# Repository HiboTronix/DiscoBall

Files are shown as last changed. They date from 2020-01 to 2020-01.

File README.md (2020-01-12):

# Discoball 
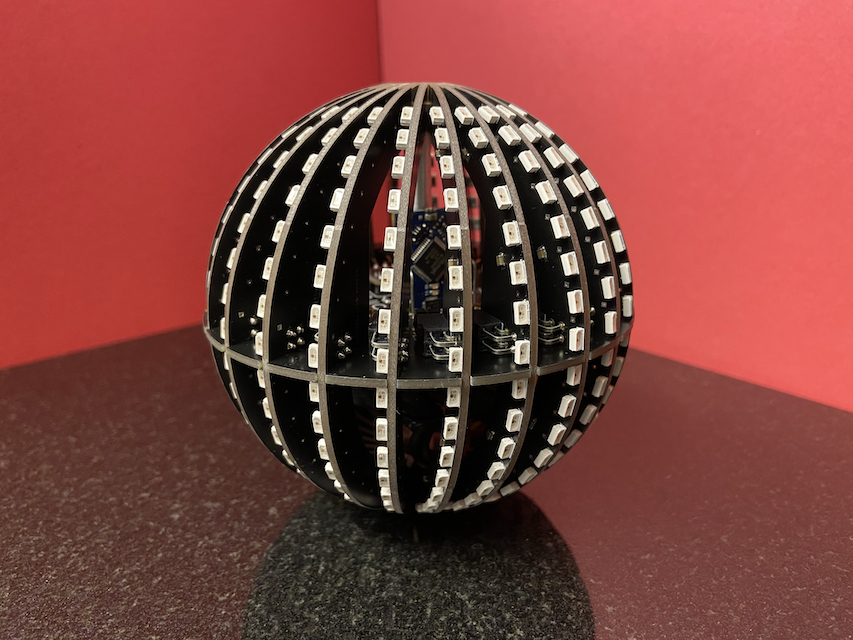
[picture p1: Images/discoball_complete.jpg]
DiscoBall

</p>Here are the DIY files so you can build your own DiscoBall.
There are 3 main parts to DiscoBall, the centre, the alignment caps and the ribs.
These files don't include a portable power solution.  I used a dc-dc converter, a lipo battery and charger that I could fit inside.</p>
<p>An Adafruit Powerboost1000  with a TP4056 lipo charger (with protection) should be ample if you use the standard brightness of 10.</p>
</p>Reference images are in the images folder.</p>
</p>Arduino IDE setup instructions are in the Software folder.</p>
</p>All the parts you require including the Gerbers required to have the PCBs manufactured are above, start by reading the assembly pdf.</p>
</p></p>
</p>I wish you luck and I'd love to see it if you make one, catch me on Twitter(@HiboTronix) and/or tag it with #Discoball : )</p>
<p><br />This work is licensed under a <a rel="license" href="http://creativecommons.org/licenses/by-sa/3.0/">Creative Commons Attribution-ShareAlike 3.0 Unported License</a>.</p>

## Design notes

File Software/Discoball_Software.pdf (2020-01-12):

# HiboTronix DiscoBall Software

The DiscoBall uses the Arduino Nano Every with the Arduino IDE.
The Library used to communicate with the LSM6DS3 is from Sparkfun, please use the guide below to install and use the “MinimalistExample” sketch in the examples folder to test the Accelerometer and Gyro.

https://learn.sparkfun.com/tutorials/lsm6ds3-breakout-hookup-guide/all#
(*Communication by I2C, address= 0x6B, INT1 connected to D4 on the Arduino)

The NeoPixels are controlled by the Adafruit NeoPixel Library:

https://learn.adafruit.com/adafruit-neopixel-uberguide/the-magic-of-neopixels

Please Install and run the “Strandtest” sketch in the examples folder with the following settings:

And also:

Power consumption at brightness 10 is approximately 550mA. If you are powering from USB and you select a higher brightness it will probably destroy your USB port.

Full brightness is approximately 6A at full white!!

The rest of the programming is up to you I’m afraid, good luck ;)

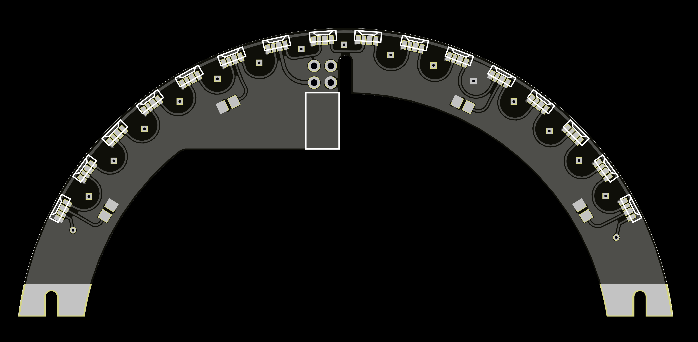
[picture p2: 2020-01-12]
Images/DiscoBall_Rib_PCB.png

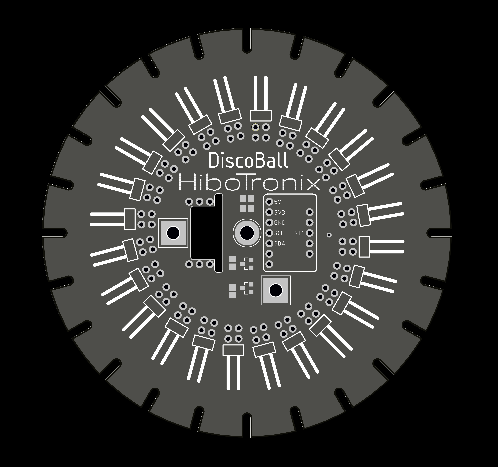
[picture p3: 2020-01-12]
Images/DiscoBall_Centre_PCB.png

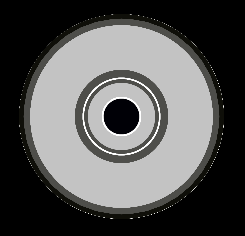
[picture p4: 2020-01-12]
Images/DiscoBall_Caps.png

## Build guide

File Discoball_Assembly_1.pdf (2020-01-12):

# HiboTronix Discotiall Assembly

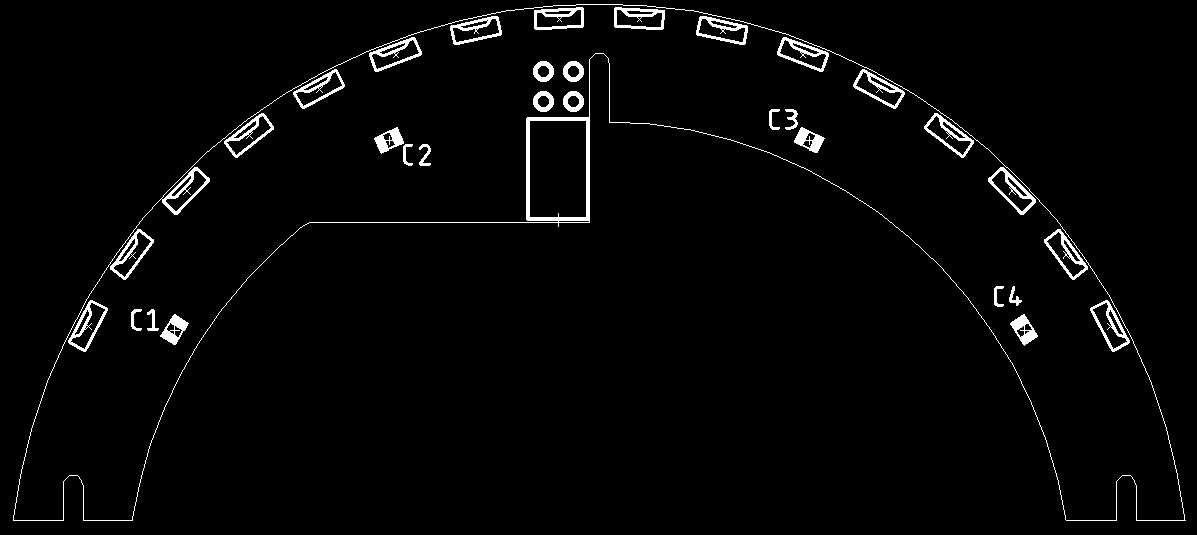
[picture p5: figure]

## Parts Required:

## SMD Components

## Other Items

(These LEDs can be obtained from AliExpress and EBAY, possibly other places too!)

## PCB And Stencil

You need the following:

24x Discotiall LED Ribs PCBs

Gerber files can be found on GitHub (https://github.com/HiboTronix/Discoball)

Files for the LED Ribs are in folder: Disctiall_Rib_PCB.zip Files for the SMD stencil are in folder: Discotiall_Rib_Stencil.zip

## Assembly:

1) Paste and assemble SMD components to board
Designator | Part | Qty | Example Link
C1,C2,C3,C4 | 0805 100nF(0.1uF) CAPACITOR | 96 | Digikey (https://www.digikey.com/short/zc128h)
Description | Qty
SK6812-SIDE-4020 LEDs | 384

2) Place the 2x2 pin header in the PCB from the LED side, using something to hold it aligned with the edge of the board and the silkscreen, solder it in.
3) Repeat 24 times.
4) My advice would be to test each rib individually before final assembly, I had an old Arduino UNO with some male to male Dupont cables as a temporary test jig.

Once you have 24 assembled and tested ribs, use the instructions in Discotiall_Assembly_2.pdf to complete your Discotiall.

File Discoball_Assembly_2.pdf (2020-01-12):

# HiboTronix DiscoBall Assembly

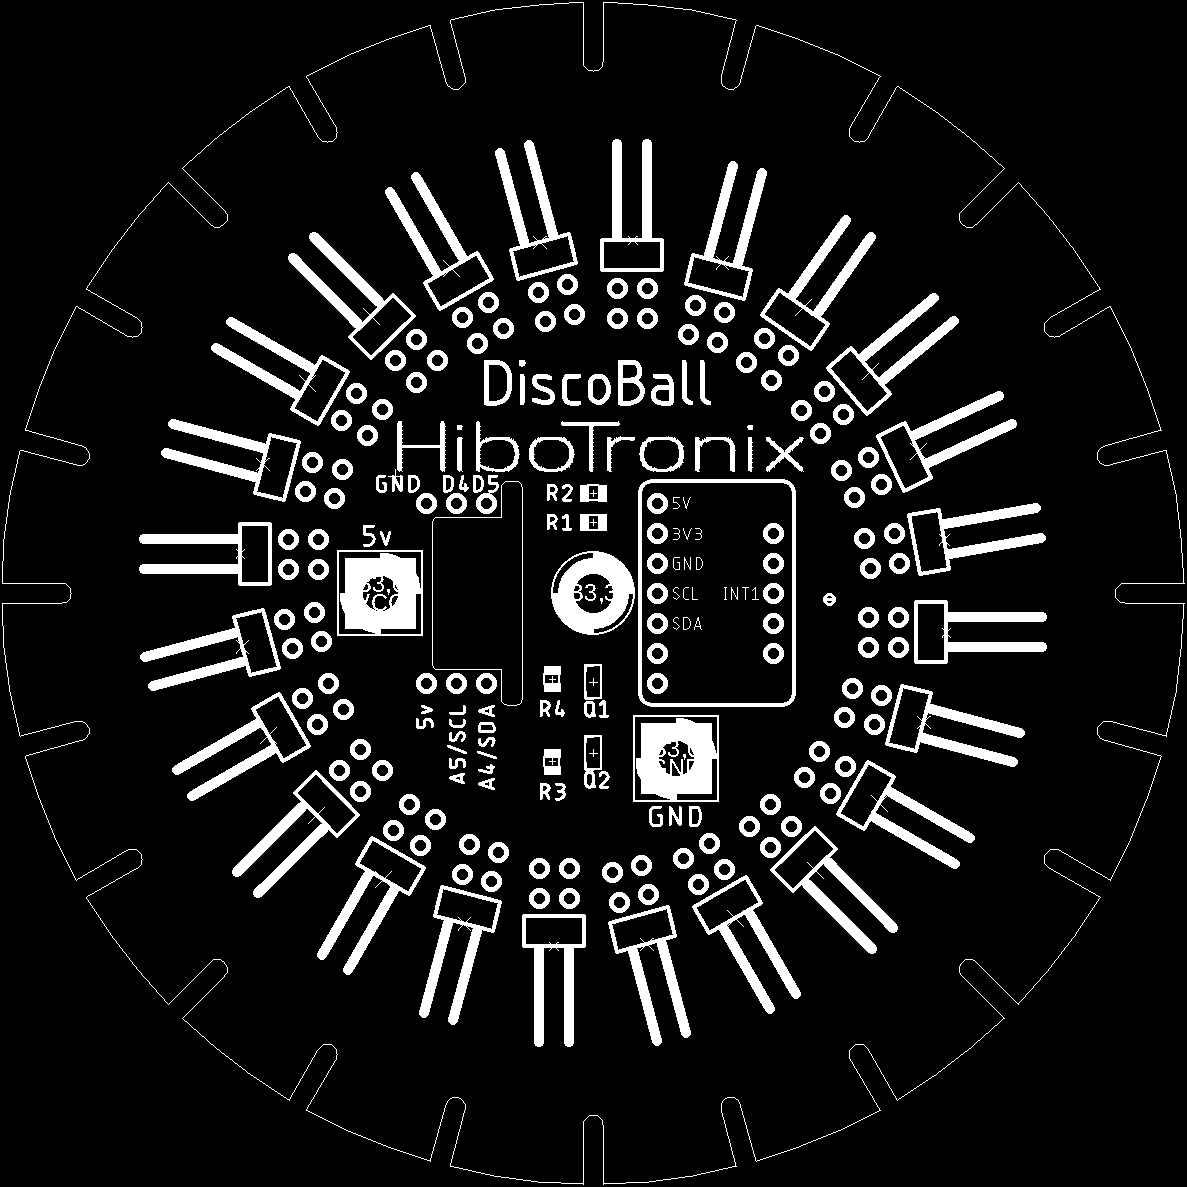
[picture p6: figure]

## Parts Required:

## SMD Components

Designator | Part | Example Link
R1,R2 | 0805 470Ω RESISTOR | Digikey (https://www.digikey.com/short/zc1rjb)
R3,R4 | 0805 10KΩ RESISTOR | Digikey (https://www.digikey.com/short/zc1rp9)
Q1,Q2 | SOT-23-3 BSS138 N-TYPE MOSFET | Digikey (https://www.digikey.com/short/zc1rz7)

## Through-hole Components

## Other Items

## PCB And Stencil

You need the following:

1x DiscoBall Centre PCB
2x DiscoBall Top & Bottom Alignment Cap PCBs 1x DiscoBall Centre SMD Stencil(Optional)
24x DiscoBall LED Ribs PCBs(Assembled)

Gerber files can be found on GitHub (https://github.com/HiboTronix/Discoball)

Files for the PCB are in folder: DiscoBall_Centre_PCB.zip
Files for the SMD stencil are in folder: DiscoBall_Centre_Stencil.zip
Files for the top and bottom alignment caps are in folder: DiscBall_Caps_PCB.zip Files for the LED Ribs are in folder: DiscBall_Rib_PCB.zip
Files for the SMD stencil are in folder: DiscoBall_Rib_Stencil.zip

## Assembly:

1) Paste and assemble SMD components to board
2) Solder headers to the LSM6DS3 module. Once complete, insert module into centre PCB footprint and solder this in.
3) Bend the 6 resistor legs at right angles roughly in the centre. With the centre PCB SMD components facing up, hold the Arduino Nano Every with the USB port facing down, insert the six resistor legs into D4,D5,A4,A5,GND & 5V on the Arduino. Slide the Arduino into the cutout in the centre PCB carefully passing the other end of the resistor legs through the corresponding pads on the centre PCB.
4) While holding the Arduino at 90deg to the centre PCB solder all resistor legs to bothe the Arduino and the centre PCB
5) Starting with the threaded rod, build up the centre support in the following order:
NUT
WASHER
ALIGNMENT CAP PCB
Part | Example Link
Arduino Nano Every | Arduino (https://store.arduino.cc/usa/nano-every)
LSM6DS3 Acc/Gyro Module | Ebay.com (https://www.ebay.com/itm/LSM6DS3-IIC-SPI-3-Axis-Accelerometer-Gyroscope-6-Degrees-Sensor-Transfer-Module/182874495175)
2x2 Right Angle Pin Header (x24) | Digikey (https://www.digikey.com/short/zc1rhp)
Description | Qty
Aluminium Tube, 43mm long, 6mm(1/4in) OD, 3mm(1/8in) ID | 2
100mm(4in) M3(4-40) Threaded Rod | 1
M3(4-40) Washers | 2
M3(4-40) Nuts | 2
Cutoff Resistor Legs Or Stiff Enamelled Equipment Wire, A Minimum Of 25mm Long. | 6

43MM SPACER
CENTRE PCB
43MM SPACER
ALIGNMENT CAP PCB
WASHER
NUT
Make sure the assembly is central on the threaded rod and gently tighten the nuts.
DO NOT OVER-TIGHTEN!
6) Using an assembled DiscoBall Rib to help with alignment, solder all 4-pin headers(x24) to the centre PCB. Use the same Rib to align all headers, don’t leave the ribs installed at this point as you won’t be able to access the other terminals for soldering.
7) Time to test, use a multimeter to make sure you have no shorts. Plug Arduino into computer and test the basic sketches starting with the LSM6DS3 test sketch. The guide to the Arduino Sketches/Libraries and recommended settings is on GitHub (https://github.com/HiboTronix/Discoball) in the Software folder.
8) Connect your power source to the large 5v & GND terminals on the centre PCB.
9) Assemble all ribs onto centre PCB making sure all slots are aligned.
10) Once Assembled tighten up the nuts a little more for rigidity.

If you have made it this far you’re a HERO!

Enjoy your DiscoBall :)

Send me a picture on Twitter @HiboTronix. I’m always looking for the tag #Discoball too.

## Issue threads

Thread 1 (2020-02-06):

Source Files

blackketter, 2020-02-06:
This project is awesome.  Will you be providing the source CAD and software files for folks to build upon your excellent work?

For me, I'd be interested building a version that uses an ESP32 as the controller to connect it to the world.

Thanks!

HiboTronix, 2020-02-06:
The schematic and board files may be released after cleanup, It's not a high priority at the moment, but I will let you know if/when it happens :)

In reference to adding an ESP32 inside, I already tried an 8266, unfortunately the balls ground plane acts as a Faraday cage and severely effects WiFi range, you'll be lucky to get 1-2 feet(if any).

If you wanted to confirm this for yourself the Arduino Nano 33 IoT version comes with a UBLOX NINA W102 which is an ESP32, I haven't checked, but it might fit in place of the Nano Every.

Closed 2020-05-28.
